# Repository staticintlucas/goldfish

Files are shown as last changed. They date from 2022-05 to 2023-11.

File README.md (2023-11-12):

# Goldfish v2

> [!NOTE]\
> The main branch contains the design for Goldfish v2. The Goldfish v1 design is available in the [v1 branch](https://github.com/staticintlucas/goldfish/tree/v1)

Goldfish is a Pro Micro compatible microcontroller board designed for use in mechanical keyboards. It is based on the same Atmel ATMega32U4 chip and is programmable using the Arduino IDE or a keyboard specific firmware such as TMK or QMK. Of course it is perfectly usable for any other electronics projects too, not just keyboards.

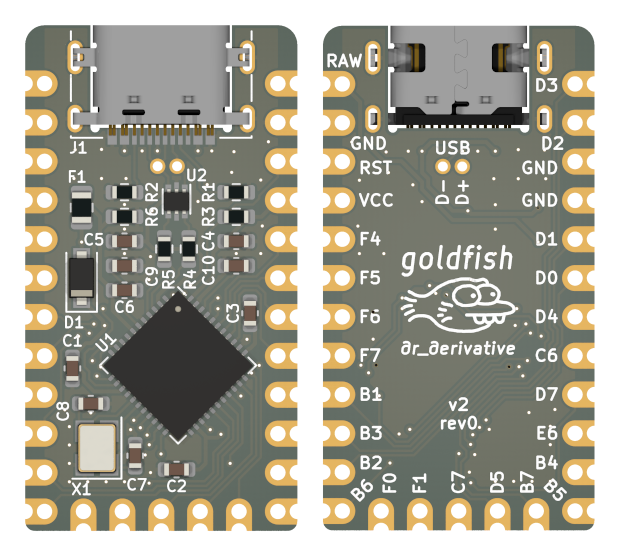
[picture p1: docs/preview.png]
preview


## Links

- [PCB Source Files](cad)

- [Schematic](docs/schematic.pdf)

- [BOM](BOM.csv)

## Features

- Lower board profile with the mid-mounted USB-C connector
- Two internal pins make the USB data lines easily accessible
- USB-C is more durable, reversible and just plain cool
- 5 additional pins on the bottom edge of the board
- Pin-compatible with the original Pro Micro
- Sturdier through-hole USB connector
- On board ESD protection for USB lines

## Changes compared to Goldfish v1

- Addition of on board ESD protection and fuse
- All 0603 resistors and capacitors for (slightly) easier hand assembly
- Castellated edge connectors similar to the Elite-C
- Less obscure USB-C connector
  - Use of more commonly available components in 2022
  - Choice between multiple compatible connectors and suppliers
  - Uses USB 2.0-only connector for easier and cheaper assembly

## USB-C Connectors

| Manufacturer | Part number | | | |
|:--- |:---:|:---:|:---:|:---:|
| Molex | 216990-0001 | - | 216990-0003 | 216990-0002 |
| HRO | - | TYPE-C-31-M-13C | TYPE-C-31-M-13B | TYPE-C-31-M-13A |
| GCT | USB4520 | USB4510 | USB4505 | USB4500 |
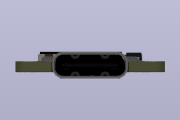
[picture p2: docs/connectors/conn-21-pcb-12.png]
c21p12
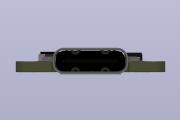
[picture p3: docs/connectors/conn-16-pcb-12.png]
c16p12
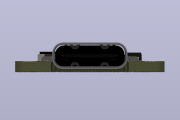
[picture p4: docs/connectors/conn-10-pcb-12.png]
c10p12
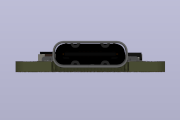
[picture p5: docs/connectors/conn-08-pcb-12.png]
c08p12
| Approx. thickness<br>1.2 mm PCB | <br>3.2 mm | <br>3.2 mm | <br>3.4 mm | <br>3.6 mm |
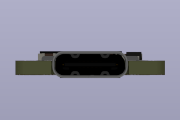
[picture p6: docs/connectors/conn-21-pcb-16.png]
c21p16
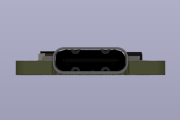
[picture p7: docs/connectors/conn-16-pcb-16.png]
c16p16
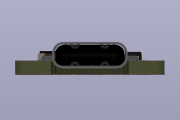
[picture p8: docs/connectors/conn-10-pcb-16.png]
c10p16
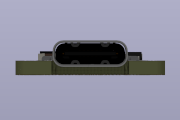
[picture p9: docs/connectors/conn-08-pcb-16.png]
c08p16
| Approx. thickness<br>1.6 mm PCB | <br>3.2 mm | <br>3.2 mm | <br>3.8 mm | <br>4.0 mm |

[c21p12]: docs/connectors/conn-21-pcb-12.png
[c16p12]: docs/connectors/conn-16-pcb-12.png
[c10p12]: docs/connectors/conn-10-pcb-12.png
[c08p12]: docs/connectors/conn-08-pcb-12.png
[c21p16]: docs/connectors/conn-21-pcb-16.png
[c16p16]: docs/connectors/conn-16-pcb-16.png
[c10p16]: docs/connectors/conn-10-pcb-16.png
[c08p16]: docs/connectors/conn-08-pcb-16.png

## Limitations compared to a Pro Micro

- No onboard RX, TX LEDs
- No onboard voltage regulator (this makes no difference for keyboards; a regulator is only required when power supplies of over 5.5V are used)

## Vendors Selling Goldfish

#### Goldfish v1 rev. C

- [BeeKeeb]

#### Comet (modified design based on Goldfish v1; see related projects)

- [Tokas' Kable Works]

**Note:** These products are sold by 3rd party vendors and are not 'officially' endorsed by me. I'm simply listing them here for convenience.

[beekeeb]: https://shop.beekeeb.com/product/goldfish-rev-c-open-source-pro-micro-replacement/
[tokas' kable works]: https://shop.tokas.co.uk/product/comet-usb-c-microcontroller/

*(Also please let me know if anything is missing from this list)*

## Related Projects

#### [Alvaro] by Ariamelon

- A modified Goldfish v1 using 0603 components instead of 0402

#### [Comet] by Tokas

- A modified Goldfish v1 using a HRO TYPE-C-31-M-12 connector

#### [Whale] by Jia Geng Chang

- A modified Goldfish v1 using a Jing 918-418K2024S40000 connector

#### [Goldfish-clone-JLCPCB] by Jeremy J Starcher

- A modified Goldfish v1 designed to meet JLCPCB's assembly requirements

#### [Elite-C] from keeb.io

- An unrelated and closed source project with similar design goals

[alvaro]: https://github.com/Ariamelon/Alvaro
[comet]: https://github.com/vattern/comet
[whale]: https://github.com/JiaGengChang/Whale
[elite-c]: https://keeb.io/products/elite-c-low-profile-version-usb-c-pro-micro-replacement-atmega32u4
[goldfish-clone-jlcpcb]: https://github.com/JeremyJStarcher/Goldfish-clone-JLCPCB

*(Please let me know if anything is missing form this list)*

## License

Released under the Creative Commons Attribution Share-Alike 4.0 License.
https://creativecommons.org/licenses/by-sa/4.0/

Original Arduino Mini Design by Team Arduino.
Arduino Pro Mini Design by Spark Fun Electronics.
Pro Micro Design by Spark Fun Electronics.
Goldfish Design by Lucas Jansen.

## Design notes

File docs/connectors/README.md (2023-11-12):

| Manufacturer | Part number | | | |
|:--- |:---:|:---:|:---:|:---:|
| Molex | 216990-0001 | - | 216990-0003 | 216990-0002 |
| HRO | - | TYPE-C-31-M-13C | TYPE-C-31-M-13B | TYPE-C-31-M-13A |
| GCT | USB4520 | USB4510 | USB4505 | USB4500 |
| Approx. thickness<br>1.2 mm PCB | c21p12<br>3.2 mm | c16p12<br>3.2 mm | c10p12<br>3.4 mm | c08p12<br>3.6 mm |
| Approx. thickness<br>1.6 mm PCB | c21p16<br>3.2 mm | c16p16<br>3.2 mm | c10p16<br>3.8 mm | c08p16<br>4.0 mm |

[c21p12]: conn-21-pcb-12.png
[c16p12]: conn-16-pcb-12.png
[c10p12]: conn-10-pcb-12.png
[c08p12]: conn-08-pcb-12.png
[c21p16]: conn-21-pcb-16.png
[c16p16]: conn-16-pcb-16.png
[c10p16]: conn-10-pcb-16.png
[c08p16]: conn-08-pcb-16.png

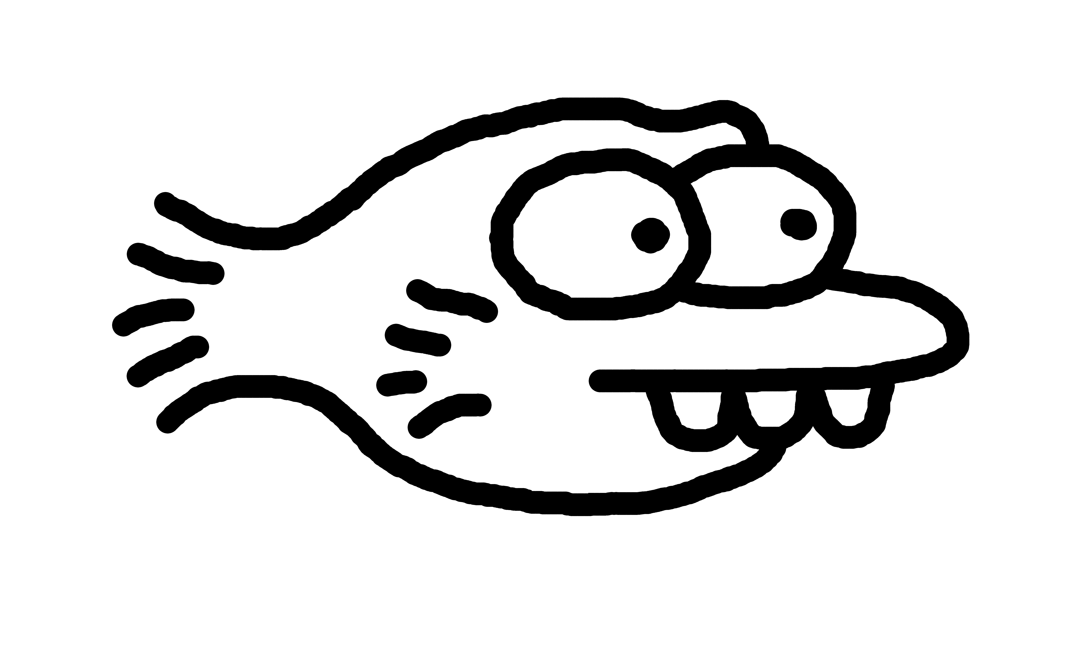
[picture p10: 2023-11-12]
artwork/fish.png

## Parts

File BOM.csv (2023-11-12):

Item # | Designator | Quantity | Manufacturer | Part # | Value | Package | Type | Notes
1 | C1,C2,C3,C4,C5,C10 | 6 |  |  | Cap 0u1 10% | 0603 | SMD
2 | C6 | 1 |  |  | Cap 4u7 10% | 0603 | SMD
3 | C7,C8 | 2 |  |  | Cap 22p 5% | 0603 | SMD
4 | C9 | 1 |  |  | Cap 1u 10% | 0603 | SMD
5 | D1 | 1 |  |  | Schottky Diode 1A | SOD-123FL | SMD
6 | F1 | 1 |  |  | Resettable Fuse 12V 500mA | 0805 | SMD
7 | J1 | 1 | Molex | 2169900001 | USB 2.0 Type C Receptacle Mid Mount |  | SMD/THT
7 | J1 | 1 | GCT | USB4520-03-0-A | USB 2.0 Type C Receptacle Mid Mount |  | SMD/THT | Alternate part for J1
7 | J1 | 1 | GCT | USB4520-03-1-A | USB 2.0 Type C Receptacle Mid Mount |  | SMD/THT | Alternate part for J1
7 | J1 | 1 | GCT | USB4510-03-1-A | USB 2.0 Type C Receptacle Mid Mount |  | SMD/THT | Alternate part for J1
7 | J1 | 1 | HRO | TYPE-C-31-M-13C | USB 2.0 Type C Receptacle Mid Mount |  | SMD/THT | Alternate part for J1
7 | J1 | 1 | Molex | 2169900003 | USB 2.0 Type C Receptacle Mid Mount |  | SMD/THT | Alternate part for J1
7 | J1 | 1 | GCT | USB4505-03-0-A | USB 2.0 Type C Receptacle Mid Mount |  | SMD/THT | Alternate part for J1
7 | J1 | 1 | HRO | TYPE-C-31-M-13B | USB 2.0 Type C Receptacle Mid Mount |  | SMD/THT | Alternate part for J1
7 | J1 | 1 | Molex | 2169900002 | USB 2.0 Type C Receptacle Mid Mount |  | SMD/THT | Alternate part for J1
7 | J1 | 1 | GCT | USB4500-03-0-A | USB 2.0 Type C Receptacle Mid Mount |  | SMD/THT | Alternate part for J1
7 | J1 | 1 | GCT | USB4500-03-1-A | USB 2.0 Type C Receptacle Mid Mount |  | SMD/THT | Alternate part for J1
7 | J1 | 1 | HRO | TYPE-C-31-M-13A | USB 2.0 Type C Receptacle Mid Mount |  | SMD/THT | Alternate part for J1
8 | R1,R2 | 2 |  |  | Res 5k1 1% | 0603 | SMD
9 | R3,R6 | 2 |  |  | Res 10k 1% | 0603 | SMD
10 | R4,R5 | 2 |  |  | Res 22R 1% | 0603 | SMD
11 | U1 | 1 | Microchip | ATmega32U4-MU | MCU 8-bit 16MHz 32K Flash | QFN44 7x7mm 0.5mm pitch | SMD
12 | U2 | 1 | ST | USBLC6-2P6 | ESD Suppression TVS Diodes | SOT-666 | SMD
13 | X1 | 1 |  |  | Crystal 16MHz 18pF | SMD3225 4P | SMD

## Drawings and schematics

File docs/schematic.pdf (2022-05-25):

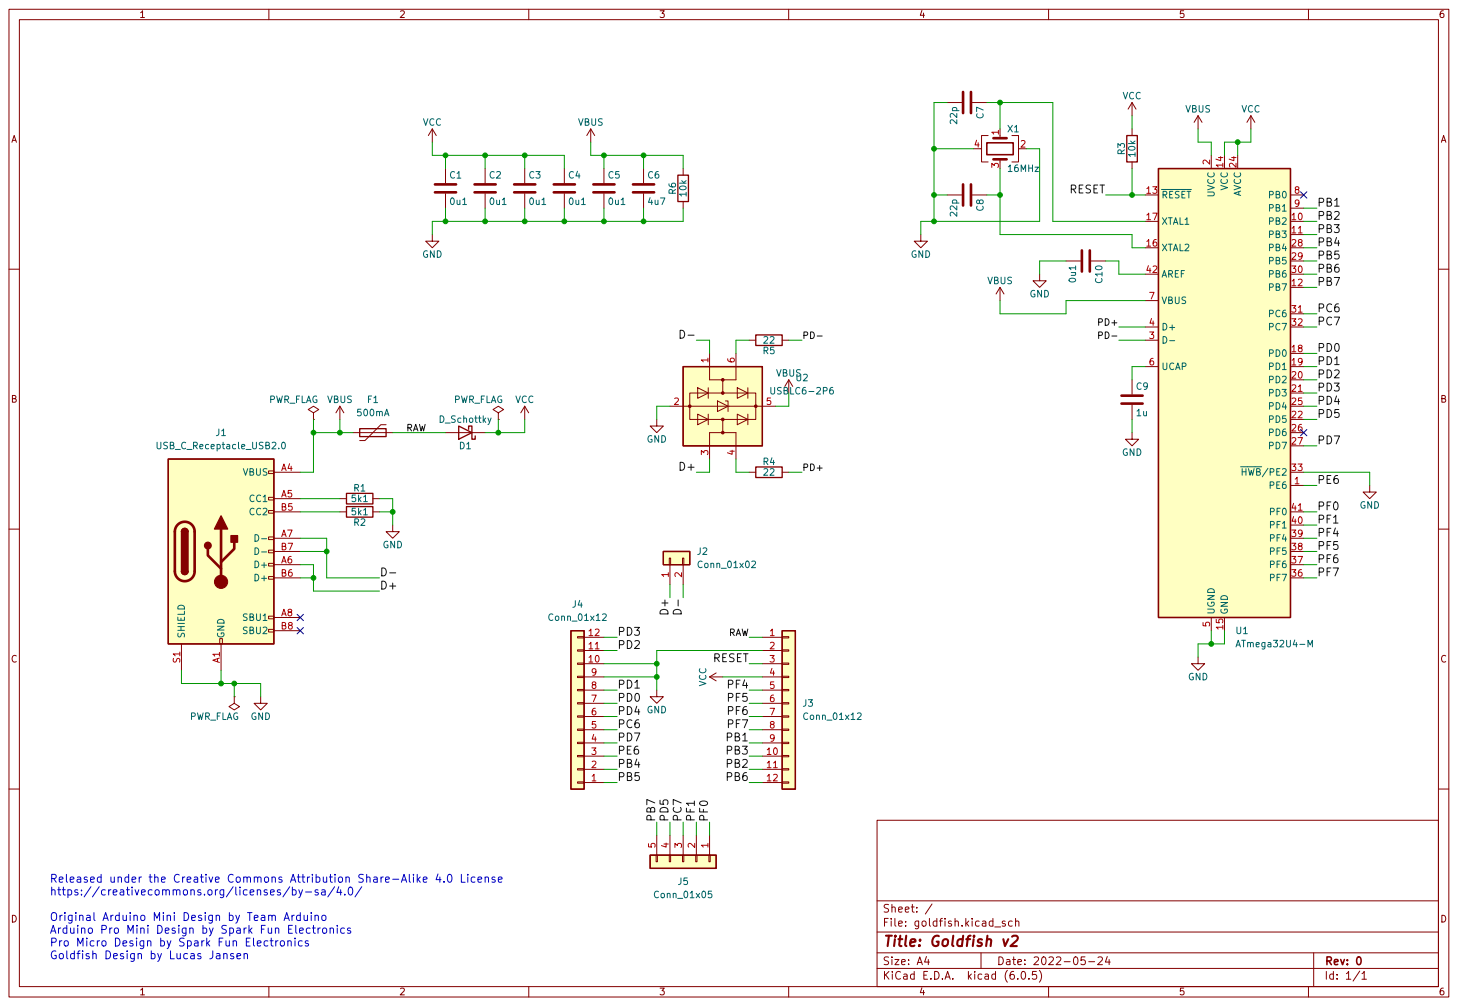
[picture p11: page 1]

2 PD2 20 PD3 21 PD5 22 AVCC 24 PD4 25 PD6 26 PD7 27 PB4 28 PB5 29 D- 3 PB6 30 PC6 31 PC7 32 ~{HWB}/PE233 PF7 36 PF6 37 PF5 38 PF4 39 D+ 4 PF1 40 PF0 41 AREF 42 UGND

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

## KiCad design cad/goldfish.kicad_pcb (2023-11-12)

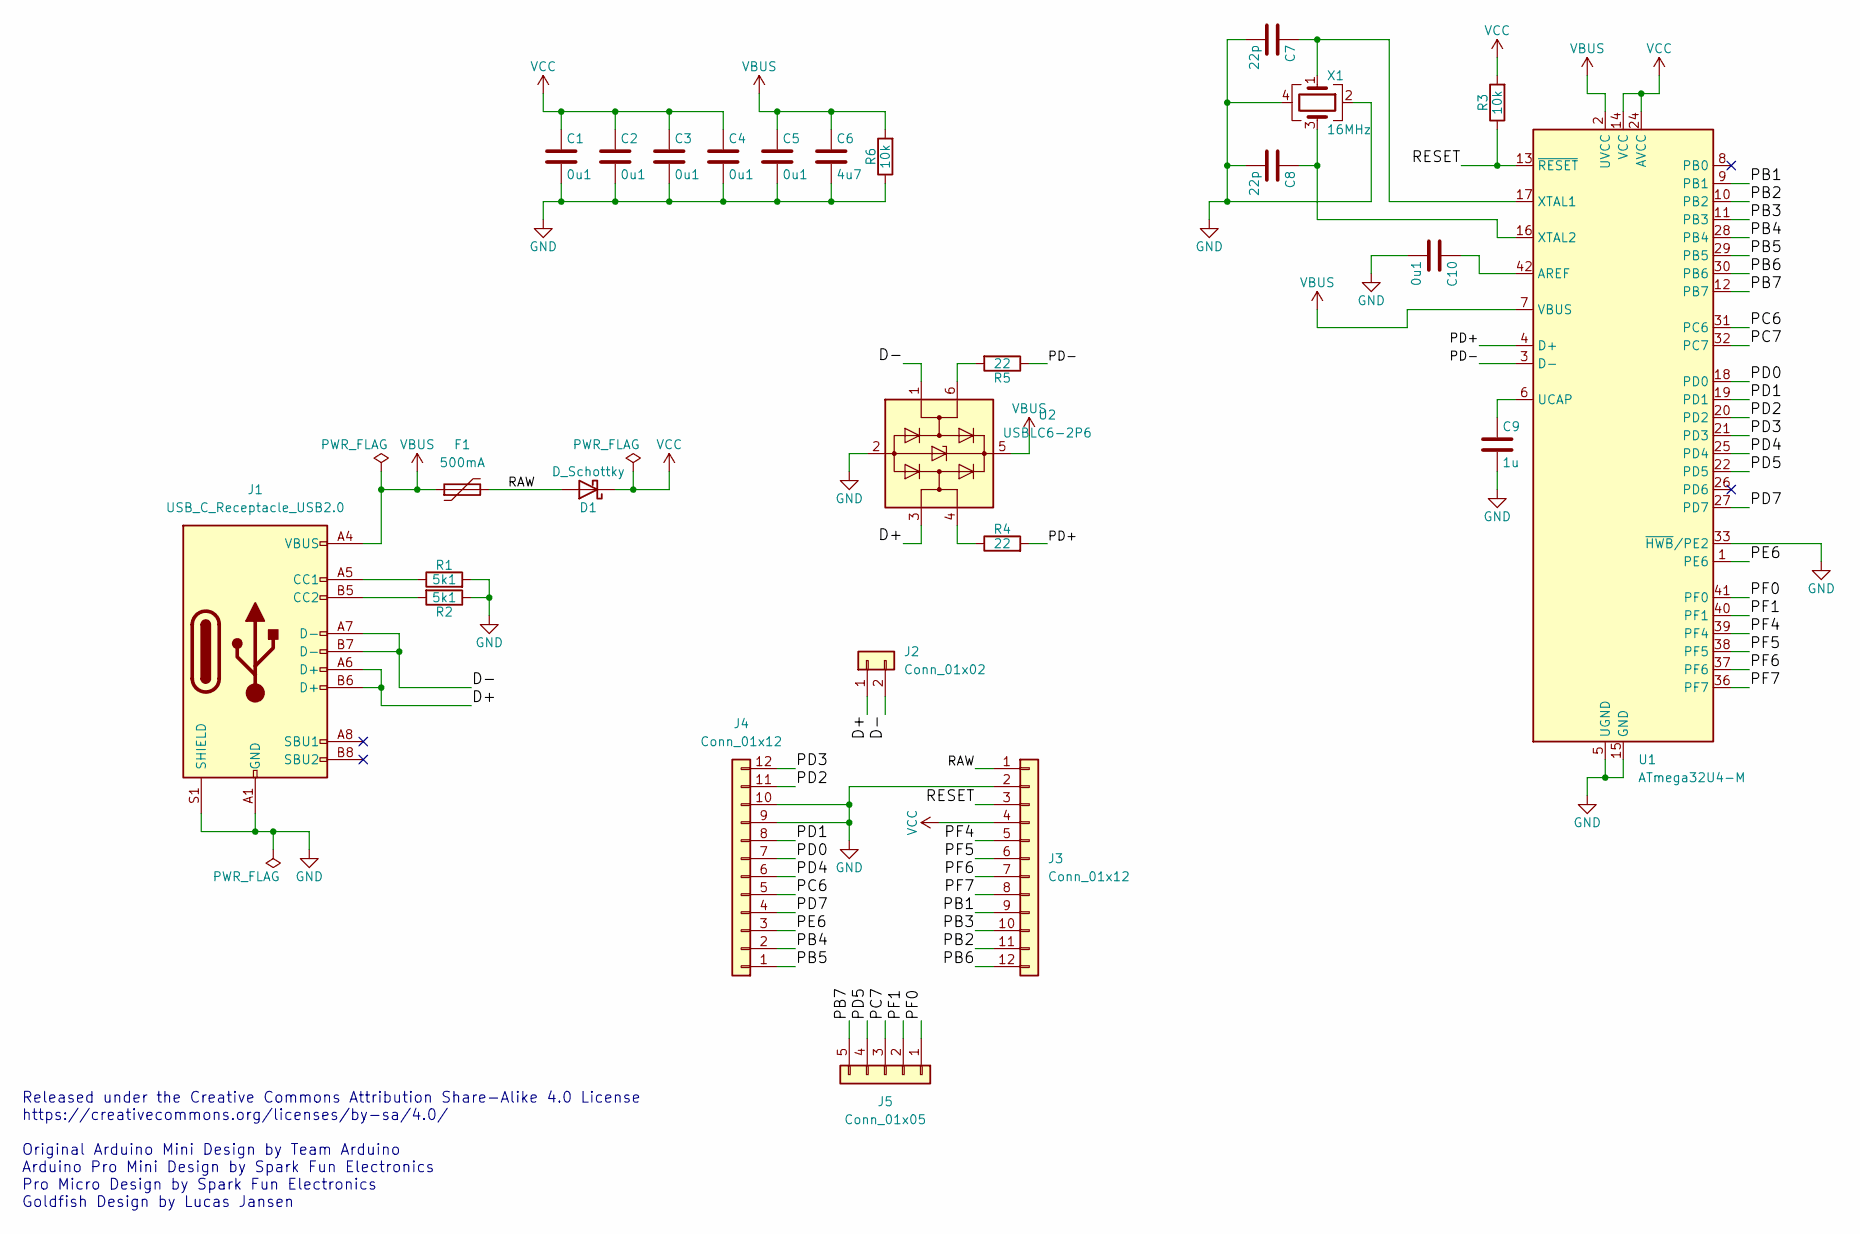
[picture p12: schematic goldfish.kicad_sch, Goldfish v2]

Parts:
C1, C2, C3, C4, C5, C10: 0u1; C_0603_1608Metric
C6: 4u7; C_0603_1608Metric
C7, C8: 22p; C_0603_1608Metric
C9: 1u; C_0603_1608Metric
D1: D_Schottky; D_SOD-123F
F1: 500mA; Fuse_0805_2012Metric
J1: USB_C_Receptacle_USB2.0; Molex-216990_GCT-USB45xx_HRO-TYPE-C-31-M-13x
J2: Conn_01x02; Pins_USB
J3, J4: Conn_01x12; Pins_x12_Castellated
J5: Conn_01x05; Pins_x05_Castellated
R1, R2: 5k1; R_0603_1608Metric
R3, R6: 10k; R_0603_1608Metric
R4, R5: 22; R_0603_1608Metric
U1: ATmega32U4-M; QFN-44-1EP_7x7mm_P0.5mm_EP5.2x5.2mm
U2: USBLC6-2P6; SOT-666
X1: 16MHz; Crystal_SMD_SeikoEpson_FA238-4Pin_3.2x2.5mm

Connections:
/D+: J1.A6 (D+), J1.B6 (D+), J2.1, U2.3 (I/O2)
/D-: J1.A7 (D-), J1.B7 (D-), J2.2, U2.1 (I/O1)
/PB1: J3.9, U1.9 (PB1)
/PB2: J3.11, U1.10 (PB2)
/PB3: J3.10, U1.11 (PB3)
/PB4: J4.2, U1.28 (PB4)
/PB5: J4.1, U1.29 (PB5)
/PB6: J3.12, U1.30 (PB6)
/PB7: J5.5, U1.12 (PB7)
/PC6: J4.5, U1.31 (PC6)
/PC7: J5.3, U1.32 (PC7)
/PD0: J4.7, U1.18 (PD0)
/PD1: J4.8, U1.19 (PD1)
/PD2: J4.11, U1.20 (PD2)
/PD3: J4.12, U1.21 (PD3)
/PD4: J4.6, U1.25 (PD4)
/PD5: J5.4, U1.22 (PD5)
/PD7: J4.4, U1.27 (PD7)
/PD+: R4.2, U1.4 (D+)
/PD-: R5.1, U1.3 (D-)
/PE6: J4.3, U1.1 (PE6)
/PF0: J5.1, U1.41 (PF0)
/PF1: J5.2, U1.40 (PF1)
/PF4: J3.5, U1.39 (PF4)
/PF5: J3.6, U1.38 (PF5)
/PF6: J3.7, U1.37 (PF6)
/PF7: J3.8, U1.36 (PF7)
/RAW: D1.2 (A), F1.2, J3.1
/RESET: J3.3, R3.1, U1.13 (~RESET)
GND: C1.2, C2.2, C3.2, C4.2, C5.2, C6.2, C7.2, C8.2, C9.2, C10.2, J1.A1 (GND), J1.A12 (GND), J1.B1 (GND), J1.B12 (GND), J1.S1 (SHIELD), J3.2, J4.9, J4.10, R1.2, R2.1, R6.1, U1.5 (UGND), U1.15 (GND), U1.23 (GND), U1.33 (~HWB/PE2), U1.35 (GND), U1.43 (GND), U1.45 (GND), U2.2 (GND), X1.2, X1.4
unnamed: C7.1, U1.17 (XTAL1), X1.1
unnamed: C8.1, U1.16 (XTAL2), X1.3
unnamed: C9.1, U1.6 (UCAP)
unnamed: C10.1, U1.42 (AREF)
unnamed: J1.A5 (CC1), R1.1
unnamed: J1.B5 (CC2), R2.2
unnamed: R4.1, U2.4 (I/O2)
unnamed: R5.2, U2.6 (I/O1)
VBUS: C5.1, C6.1, F1.1, J1.A4 (VBUS), J1.A9 (VBUS), J1.B4 (VBUS), J1.B9 (VBUS), R6.2, U1.2 (UVCC), U1.7 (VBUS), U2.5 (VBUS)
VCC: C1.1, C2.1, C3.1, C4.1, D1.1 (K), J3.4, R3.2, U1.14 (VCC), U1.24 (AVCC), U1.34 (VCC), U1.44 (AVCC)

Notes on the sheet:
Released under the Creative Commons Attribution Share-Alike 4.0 License https://creativecommons.org/licenses/by-sa/4.0/ Original Arduino Mini Design by Team Arduino Arduino Pro Mini Design by Spark Fun Electronics Pro Micro Design by Spark Fun Electronics Goldfish Design by Lucas Jansen

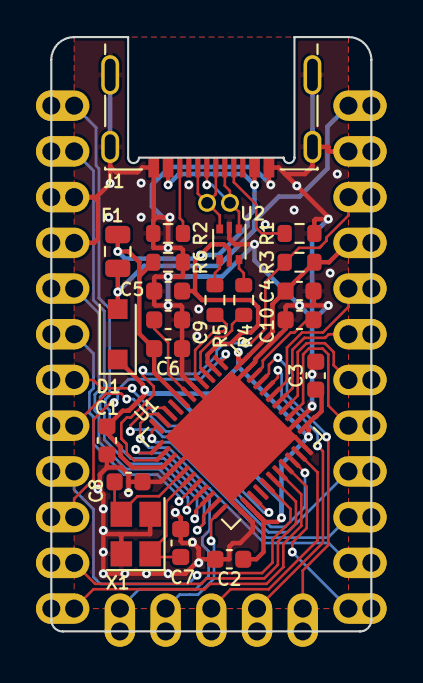
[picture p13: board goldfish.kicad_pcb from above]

Board: 2 copper layers, 17.8 x 33.0 mm, 26 parts (0 on the bottom side), 40 nets.

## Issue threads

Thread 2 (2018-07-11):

prototypes / groupbuy?

fieldju, 2018-07-11:
I found this project via https://geekhack.org/index.php?topic=93571.0, while googling pro-micro with usb-c after breaking my usb port off and having to desolder and re-solder a replacement.

Any chance there will be a group buy or ability to acquire a prototype?

brianweyer, 2018-08-11:
I'd also be interested in this.

staticintlucas, 2020-09-17:
There are a bunch of other alternatives these days so I don't see much point in running a group buy, besides I don't really have the free time to run something like that right now.

The project is open source for a reason though, so if anyone else wants to roll with it feel free.

Closed 2020-09-17.

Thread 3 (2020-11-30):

"Stole" your schematic -- designed a new board

JeremyJStarcher, 2020-11-30:
Just letting you know that I snagged a copy of your schematic and used it as the base of a pin-compatible board, but with different design goals.

Right now my project is not an official fork of yours, but that should be fairly easy to do.

If you'd rather I changed the name of my project because it has different goals than yours, I'm more then willing to do that as well.

Of course, either way, full credit will be given.

https://github.com/JeremyJStarcher/Goldfish-clone-JLCPCB

staticintlucas, 2020-11-30:
The design is licensed under CC BY-SA, so as long as you give credit and license under the same terms it's all good. You can add the copyright info to your README like I have, but you already have it in the schematic so I'm not sure if that's even necessary.

I don't mind you using Goldfish in the name at all, as long as you don't pretend that yours is the 'original' Goldfish.

If you would like to make your project an 'official' fork feel free, I really don't mind either way. We could also add it to this repo as a new branch making it an official Goldfish variant, but if you'd rather keep it in your own repo that's fine too. The choice is up to you.

JeremyJStarcher, 2020-12-01:
Thanks for the response, really appreciate it.
While I know that the file was under the CC BY-SA license, I consider it good form to contact a project owner when work is modified, so thank you for the response.

I meant to have the licence there in the README, twas just an oversight that I have corrected.

I'll wait until I get the boards back and make sure they actually work and then I will consider if I want to make things a fork of your repo or if I want to put in a pull request.

Alas, the maker is out of 32u4 at the moment, so I have to wait for a resupply before I can put in my order and make sure that everything is oriented properly.

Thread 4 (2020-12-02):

Board from JLCPCB not working

vicgwee, 2020-12-02:
First I would like to say thanks for making such a neat board, I really like it!

For a keyboard project I went to make 20 of these on JLCPCB with their PCB assembly service. I couldn't find the original crystal oscillator, so I had to change it to [this](https://datasheet.lcsc.com/szlcsc/Yangxing-Tech-X322516MLB4SI_C13738.pdf).

When the boards came, I soldered the original Hirose connector on but I couldn't get my PC or Mac to detect it at all via USB. I thought perhaps I needed to burn a bootloader, but I'm having trouble using a Nano as an ISP to flash it.

Here is the board, the solder work by JLCPCB and the traces look great.

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

laughedelic, 2020-12-02:
relevant: https://github.com/staticintlucas/Goldfish/issues/3

jankolkmeier, 2020-12-02:
I'm you want the *-AU* version of the atmega, the *-MU* version as you suspected comes without bootloader ([see here](https://ww1.microchip.com/downloads/en/DeviceDoc/Atmel-7766-8-bit-AVR-ATmega16U4-32U4_Summary.pdf)), so you'll definitely need to flash the bootloader.

How exactly did you try flashing it the bootloader so far?

jankolkmeier, 2020-12-02:
please double check for your self, but this is how I think you should connect the ISP headers:
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

staticintlucas, 2020-12-02:
It looks like something went wrong when exporting your gerbers for JLCPCB. I'm assuming you generated your own gerbers and didn't use the ones I released [here](https://github.com/staticintlucas/Goldfish/releases/tag/revC)?

If you compare the released gerbers (screenshot from gerblook.org) to your board you can see the vias that are meant to connect the grounds front and back aren't actually connected to the ground planes on your board.

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

The only real solution I can think of is to peel back some of the soldermask in these areas and bridge the gap between the vias and the plane with some solder. That's a tedious task though for 20 boards. 😧

vicgwee, 2020-12-03:
Oh no that looks bad! Yes I had to generate my own gerber because I was panelising it together with my keyboard PCB.

Thanks so much for the help, I'll see if I can get it to work.

fi0, 2020-12-04:
@vicgwee did you find out what was causing the gerber errors?

Closed 2020-12-03.

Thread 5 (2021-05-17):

Question about capacitors on VCC and VBUS

marekpiechut, 2021-05-17:
Hi, sorry for opening an issue with a question, but could not find a better place to ask.

I'm an electronics newbie, so it might be a dumb question, but I cannot figure it out. Why are you using 4 x 0.1uF capacitors on VCC and 0.1uF and 4.7uF capacitors on VBUS?

When going through the datasheet for Atmega32u4 I've found that they recommend a 10uF on VBUS (so maybe you have smaller capacitance to improve reset time on reconneciton?). There's nothing about capacitors on VCC.

I've also checked ProMicro schematics, and they have a 1uF on VCC and VBUS connected together.

Sorry if it's a dumb question, but I'm looking into it for few hours already and cannot figure it out.

marekpiechut, 2021-05-17:
Hi, sorry for opening an issue with a question, but could not find a better place to ask.

I'm an electronics newbie, so it might be a dumb question, but I cannot figure it out. Why are you using 4 x 0.1uF capacitors on VCC and 0.1uF and 4.7uF capacitors on VBUS?

When going through the datasheet for Atmega32u4 I've found that they recommend a 10uF on VBUS (so maybe you have smaller capacitance to improve reset time on reconneciton?). There's nothing about capacitors on VCC.

I've also checked ProMicro schematics, and they have a 1uF on VCC and VBUS connected together.

Sorry if it's a dumb question, but I'm looking into it for few hours already and cannot figure it out.

staticintlucas, 2021-05-17:
Hey,

The 0.1uF caps are what's known as decoupling capacitors. You can Google the term for more info, but the TL;DR is they're small caps placed close each power pin on a chip. They allow any high frequency transients or noise in the power plane to pass straight to ground so that the voltage received by the chip itself remains stable. It's a common practice for any IC, not just microcontrollers. I'm actually surprised the ATmega datasheet doesn't mention this, although I'm sure it is mentioned in some application note somewhere.

So in the schematic there is an 0.1uF cap for each of the VCC and AVCC pins, and one on VBUS for the UVCC pin. The 4.7u is for the VBUS pin. I'm not sure exactly why I didn't use 10u, it's possible I just happened to have some extra 4u7 caps around when I first designed this. For all these caps the exact value doesn't really matter too much, as long as it's the same order of magnitude it'll work just as well.

On the Pro Micro they have a 1uF on VBUS rather than 10u; I have no idea why, but I can't imagine it makes a huge difference. For VCC they use an LDO to step down the incoming 5V USB power to 3.3V, and you can see quite a few capacitors around the LDO to minimise any transients. I guess that's why they decided they didn't need decoupling caps, although it's usually good practice to keep them anyway.

I hope this has answered all you questions! And feel free to ask if you have any more 😄

marekpiechut, 2021-05-18:
I've did some reading about the subject and now it makes sense. You have 4 VCC pins on the chip, so you have 4 capacitors near it.
Learned something new :) Thanks 🙏.

Closed 2021-05-18.

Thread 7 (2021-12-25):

Me brain not so good, gerber file how?

geenoee, 2021-12-25:
I'm relatively new to CAD and all this stuff, I decided I wanted to commission a PCB so I can handwire my keyboards. I've downloaded Gerber files before but I'm having trouble specifically with this project in which my Gerber files when I plot them on KiCAD. don't actually download as Gerber files and as some other type of file. With that said the PCB manufacturer can't support those types of files. If you can, can you either put a zip of the Gerber files or explain to me what happened? pretty please and thank you for creating this masterpiece of a microcontroller. I don't know if this is the right place to talk about this but sorry if it isn't

staticintlucas, 2021-12-25:
The source files in the repo are KiCad design files. If you want Gerbers you can click on Releases on the right hand side and download the .zip with Gerber files.

geenoee, 2021-12-25:
> The source files in the repo are KiCad design files. If you want Gerbers you can click on Releases on the right hand side and download the .zip with Gerber files.

thank you so much!!!!!!

Closed 2021-12-25.

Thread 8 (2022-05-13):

Designing a 31-m-13 usb-c version

JiaGengChang, 2022-05-13:
I was building my own controller using the latest release, but realised that I do not have the Hirose type CX70M usb-C connector.  In my region, shipping of this kind of connector is quite expensive.

Hence, I am working on modifying the usb-C footprint to HRO 31-M-13, which can be purchased from aliexpress (see https://www.aliexpress.com/item/32998900371.html?spm=a2g0o.order_list.0.0.31b61802zlAvym for example). Will let you know how it goes.

staticintlucas, 2022-05-14:
Nice idea. I had been planning to redo the PCB with another connector at some point. The availability of different connectors has changed a lot since I first designed this.

If you open source your version let me know. I'll link it in the readme so others can find it more easily.

JiaGengChang, 2022-05-15:
I have made the made the modification (along with a two other minor additions).
The link is https://github.com/JiaGengChang/Whale.
I actually ended up using another USB-C connector which is the one I actually provided in the link above. Its part number on LCSC.com is C168688.
Would appreciate if you could give my adapted version a mention.

staticintlucas, 2022-05-15:
Added a link to it in the README in 2be9e98

JiaGengChang, 2022-05-16:
Thanks a lot

Closed 2022-05-16.

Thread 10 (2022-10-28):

[Question] Changes

rickyosser, 2022-10-28:
Hi,

I'm interested in your design but would like to know how hard it would be to change the design to:
1,  include an onboard voltage regulator
2, remove the USB-connector and add soldering points for +5 and GND in in addition to the data-lines

I'm not an electrical engineer and this might be a bit out of my league to do by myself.

Thanks in advance,
Rickard

staticintlucas, 2022-10-29:
If you have a little experience designing PCBs it shouldn't be too difficult to make those changes.

For the voltage regulator, you can have a look at the original Pro Micro schematic [here](http://cdn.sparkfun.com/datasheets/Dev/Arduino/Boards/Pro_Micro_v13b.pdf), which includes a voltage regulator. You don't even need to add additional soldering points for USB, there are already 2 through holes for the D+/- lines, GND can just be connected to a ground pin, and +5V to the RAW pin.

The biggest issue when designing the PCB was having enough room to fit everything in, but without the USB connector you should have plenty of room to fit the regulator.

Closed 2022-12-11.

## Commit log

2018-01-05 Rev. 0 - Initial Design
    [goldfish.kicad_pcb, goldfish.sch]
2018-01-05 Rev. A - Changed footprint of C6 from 0402 to 0603 to reduce component cost
    [goldfish.kicad_pcb, goldfish.sch]
2018-02-09 Rev. B - Fixed split keyboard issue and tidied up layout
    [goldfish.kicad_pcb, goldfish.sch]
2019-09-03 Rev. C - Changed bottom pins for Elite-C compatibility
    [goldfish.kicad_pcb, goldfish.sch]
2019-10-30 Fixed missing goldfish-rescue file error
    [goldfish.sch]
2021-03-09 Update README with link to Comet board
2022-05-16 Update gitignore for latest Kicad versions
2022-05-16 Update design files to KiCad 6.0
    [goldfish.kicad_pcb, goldfish.kicad_sch]
2022-05-23 Mention silkscreen issue
2022-05-24 Fix silkscreen on bottom edge pins
    [goldfish.kicad_pcb, goldfish.kicad_sch]
2022-05-25 Add initial V2 design
    [goldfish.kicad_pcb, goldfish.kicad_sch, goldfish.sch]
2022-05-25 Update preview image and schematic PDF
2022-05-27 Adjust USB-C connector 3D model position
    [goldfish.kicad_pcb]
2022-05-27 Adjust connector colours
2022-05-27 Add info about possible connectors to the README
2022-07-16 Switch D1 to SOD 123F
    [goldfish.kicad_pcb, goldfish.kicad_sch]
2022-07-16 Add BOM
    [BOM.csv]
2022-07-16 Forgot to recalculate ground pours
    [goldfish.kicad_pcb]
2022-07-16 v2 rev0 prerelease
    [goldfish.kicad_pcb]
2023-11-12 Add original artwork and connector models
2023-11-12 Update design files to KiCad 7
    [goldfish.kicad_pcb, goldfish.kicad_sch]
2023-11-12 Add .gitattributes for eol normalisation
    [BOM.csv, goldfish.kicad_pcb, goldfish.kicad_sch]
